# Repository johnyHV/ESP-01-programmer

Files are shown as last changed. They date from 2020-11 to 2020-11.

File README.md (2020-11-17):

# ESP-01-programmer version 1.0
Programmer for module ESP-01

If do you see in Arduino IDE console text "Connecting" then, switch GPIO0 pin to ground, ant push RESET button. 
After sucessfully upload source code to module ESP-01 please disconnect GPIO0 pin from ground, and push RESET button. 
After this step is surce code uploaded in MCU.

# ESP-01 module
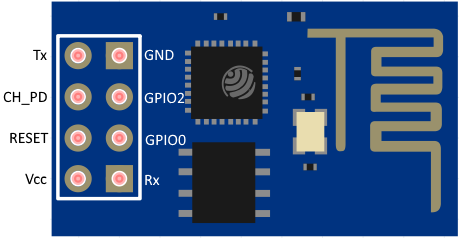
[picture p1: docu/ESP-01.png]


# USB to UART converter
Do you need this USB to UART converter, but please logic level you must set to 5V
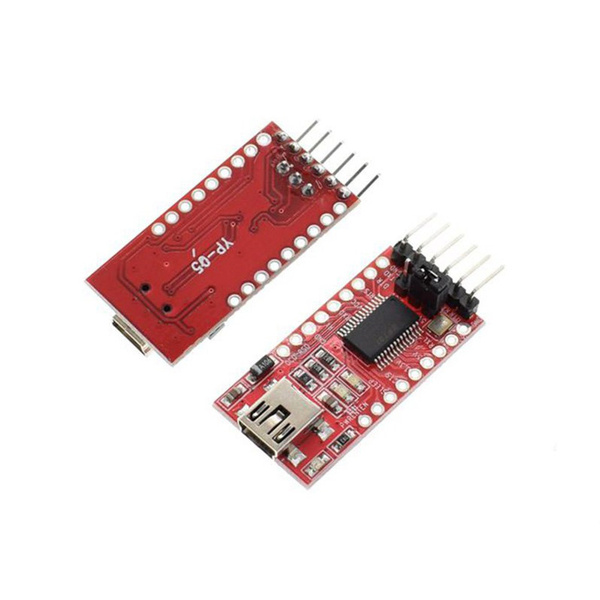
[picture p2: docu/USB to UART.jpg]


# Schematic
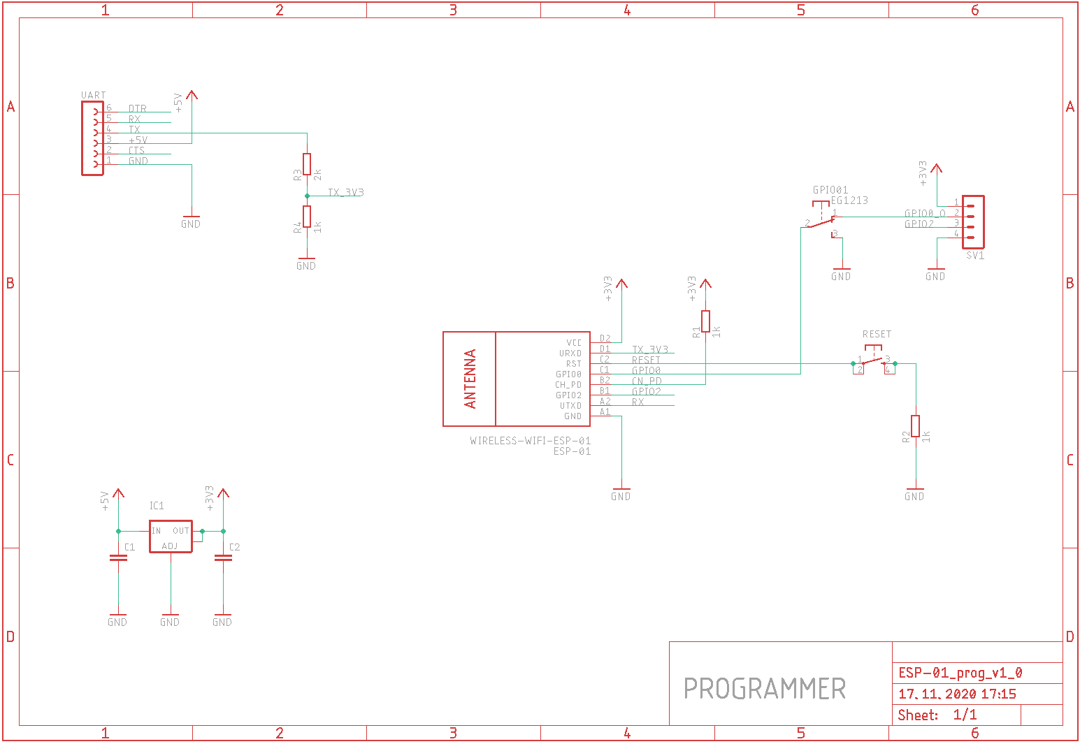
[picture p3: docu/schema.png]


# Programmer board
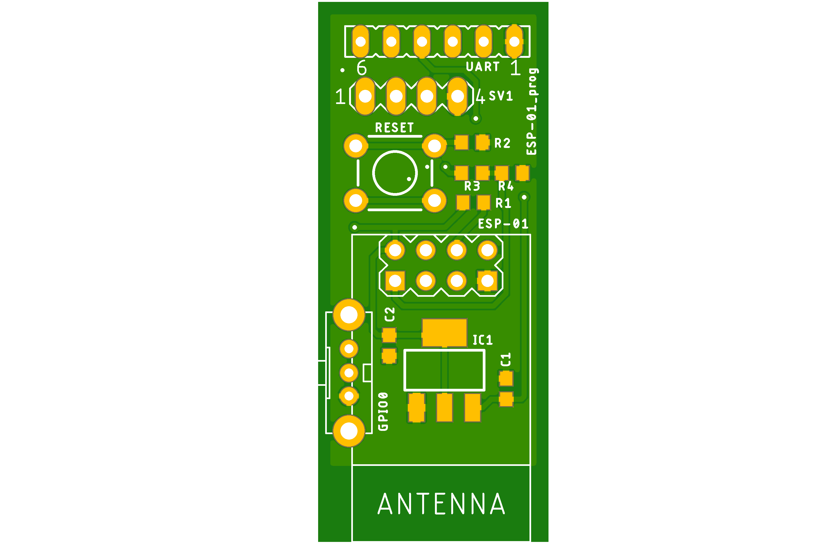
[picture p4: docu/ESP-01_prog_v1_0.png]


# Prototype version
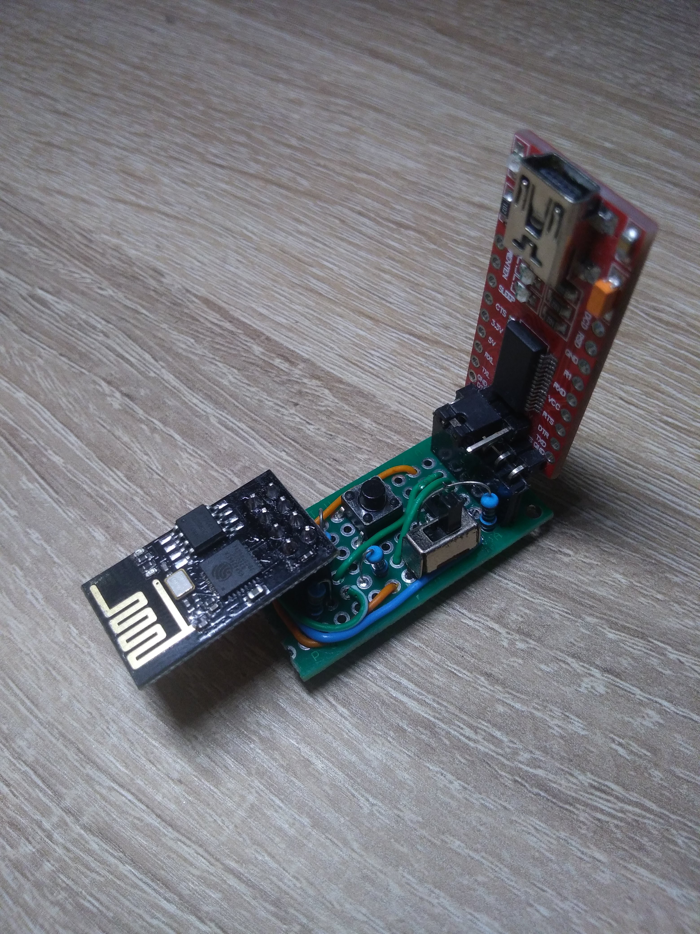
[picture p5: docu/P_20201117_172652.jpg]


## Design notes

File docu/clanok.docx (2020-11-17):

# Ako naprogramovať WI-FI čip ESP-01

Existuje veľké množstvo modulov s WI-FI čipom ESP8266, s rôznymi veľkosťami. Mňa zaujala najmenšia verzia modulu s čipom ESP8266 , a to konkrétne modul ESP-01. Tento modul je zaujímavý svojou veľkosťou a parametrami.

Opis modulu

- Veľkosť modulu približne 25x15mm
- WI-FI čip ESP8266
- veľkosť FLASH pamäte 1MB vo verzii s čiernou doskou od AI-cloud a 512kb v modrej verzii PCB, základnej manufaktúrnej verzii.
- Veľkosť sRAM pamäte 80KB
- Napájacie napätie 3,3V
- Logická úroveň pre GPIO 3,3V
- Podpora WI-FI noriem 802.11/b/g/n
- Integrovaný TCP/IP protokol stack
- Podpora WI-FI security WPA, WPA2
- 2x digitálny vstup/vystup


# Opis

Základná verzia ESP-01 od Ai-cloud používa AT príkazy pre komunikáciu s externým MCU. V tejto verzii je už napálený firmware v ESP-01, ktorý využíva pre komunikáciu s okolitým svetom AT príkazy cez UART rozhranie. Zoznam týchto AT príkazov nájdete na internete. Tieto AT príkazy podporujú napríklad pripojenie modulu k WI-FI sieti, vytvorenie AP z WI-FI modulu, pripojenie sa na TCP-IP server, pripojenie na http server, a veľa ďalšieho. V prípade, že chcete do spomínaného ESP-01 dostať vlastný firmware, a používať MCU ESP-8266 ako štandardný MCU, musíte si vyrobiť vlastný programátor. Jestvuje veľa čínskych programátorov pre ESP-01 modul, ale na tie si musíte dať pozor. Základným dôvodom je, že v čínskych e-shopoch označia za ESP-01 programátor dosku, ktorá nie je programovacia, ale je to iba USB-UART prevodník, pre prácu s AT príkazmi. Nezabudnite si dať pozor na spotrebu prúdu pre modul. MCU ESP-8266 sa považuje za „low power WI-FI MCU“, keďže môže mať v „Deep-Sleep“ móde spotrebu okolo 10uA. No pri maximálnom vyťažení môže byť spotreba prúdu až 170mA počas komunikácie s WI-FI sieťou.

# Schéma zapojenia

Schéma zapojenia pozostáva z jedného prepínača, tlačidla, stabilizátora napätia a pár rezistorov.


Stabilizátor napätia je potrebný, keďže ESP-01 potrebuje napájacie napätie 3,3V. Komunikácia s ESP-01 cez UART rozhranie tiež prebieha na napäťovej úrovni 3,3V. Pozor, štandardné Arduino komunikuje logickou úrovňou 5V, čo môže nenávratne poškodiť ESP-01 modul. Z toho dôvodu je potrebné na RX vstup modulu ESP-01 použiť napäťový delič, ktorý spraví z 5V približne 3,3V. Existujú špeciálne integrované obvody „logic level convertor“ pre upravenie napäťových úrovní, avšak v tomto prípade je postačujúci napäťový delič. Na TX výstup modulu ESP-01 nie je potrebné pridávať nič, keďže 3,3V je stále v tolerancii. Ďalej je použitý jeden prepínač, ktorým určujeme či budeme modul programovať, alebo s ním komunikovať, a taktiež tlačidlo RESET.

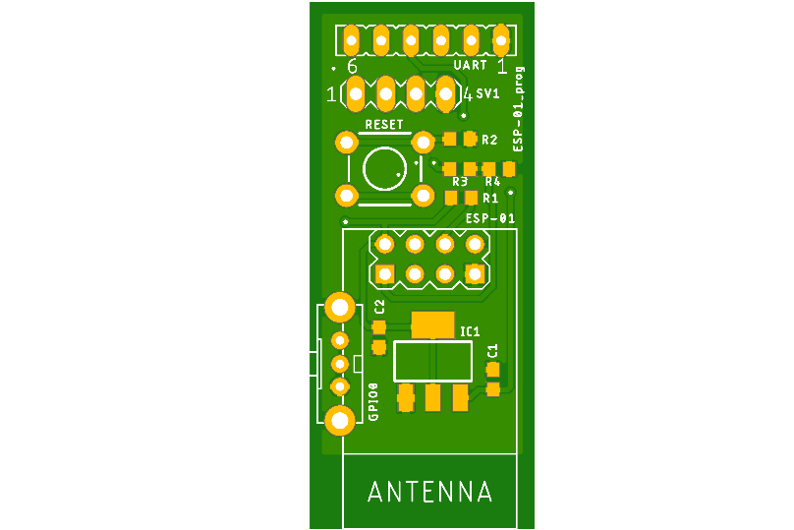
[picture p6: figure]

# Konštrukcia

Pre komunikáciu s programátorom, použijeme štandardný čínsky USB to UART prevodník, s možnosťou nastavenia logickej napäťovej úrovne. Možnosť nastavenia logickej úrovne v tomto prípade nevyužijeme. Tento prevodník využíva FT232RL čip, ale nie je vždy dodaný s originálnym čipom.


Aktuálne nemám vyrobený plošný spoj, takže som si konštrukciu osadil a otestoval na univerzálnom spájkovacom poli. Výsledný efekt so zapojeným prevodníkom a WI-FI modulom je nasledovný:

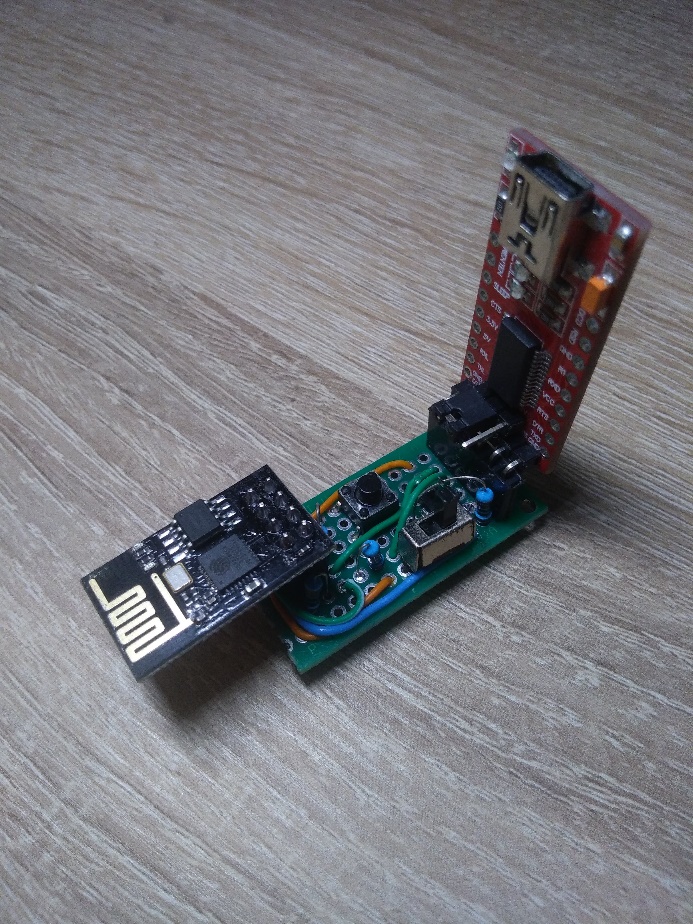
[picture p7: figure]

# Použitie

USB to UART prevodník nastavíme na logickú úroveň 5V. Vďaka tomu budeme mať na výstupe napájacie napätie z prevodníka 5V, a aj komunikáčnú logickú úroveň na 5V.

Ďalej si doinštalujeme podporu ESP8266 MCU do Arduino IDE. Nájdeme to v časti „tools-> Board -> Board manager“ kde do vyhľadávača napíšeme ESP8266 a následne si nainštalujeme podporu ESP8266 modulov.

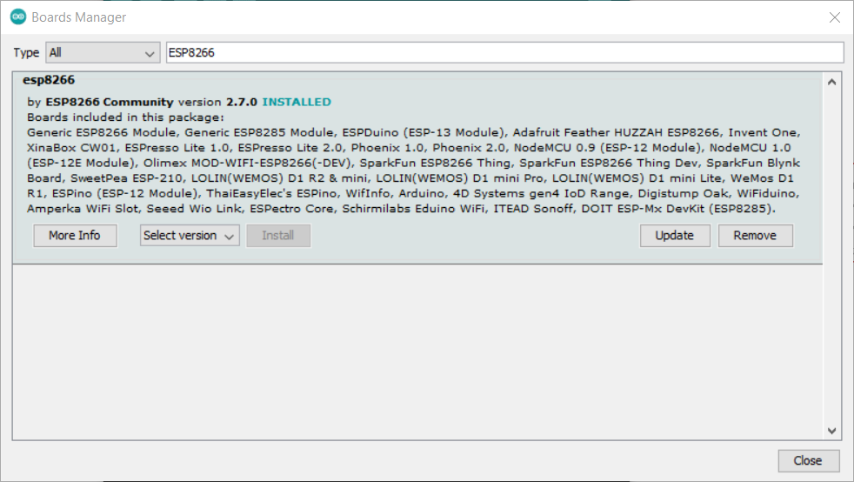
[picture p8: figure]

Následne si v časti „tools->board“ vyberieme dosku „Generic ESP8266“

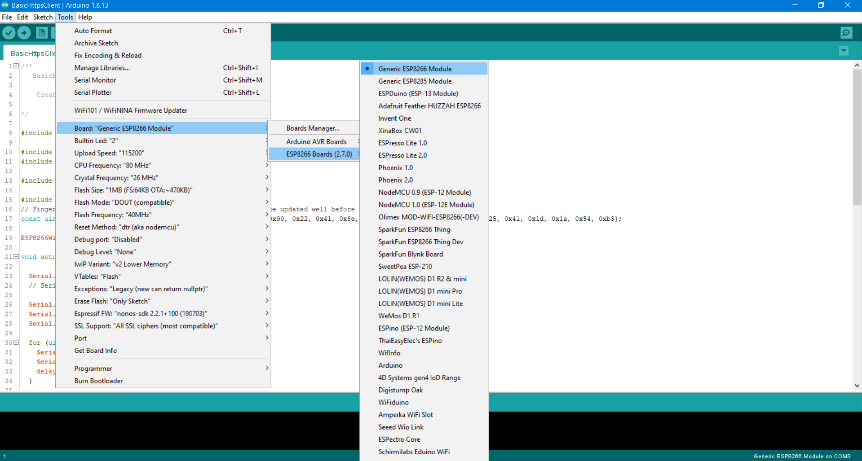
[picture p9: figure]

Môžeme si napríklad otvoriť example pre http WEB server, z „file->example->ESP8266WebServer->HelloServer“. Ostáva už iba upraviť prihlasovacie údaje pre vašu WI-FI sieť, skompilovať zdrojový kód a nahrať ho do modulu ESP-01.

Pred tým ako spustíme nahrávanie zdrojového kódu do modulu ESP-01, musíme prepnúť prepínač GPIO01 do polohy, kedy bude uzemnený GPIO01 pin. Potom stlačíme tlačidlo v Arduino IDE pre začatie kompilovania a nahrávania zdrojového kódu do MCU. Po kompilácii uvidíme v konzole, ako sa Arduino IDE pokúša spojiť s modulom ESP-01.

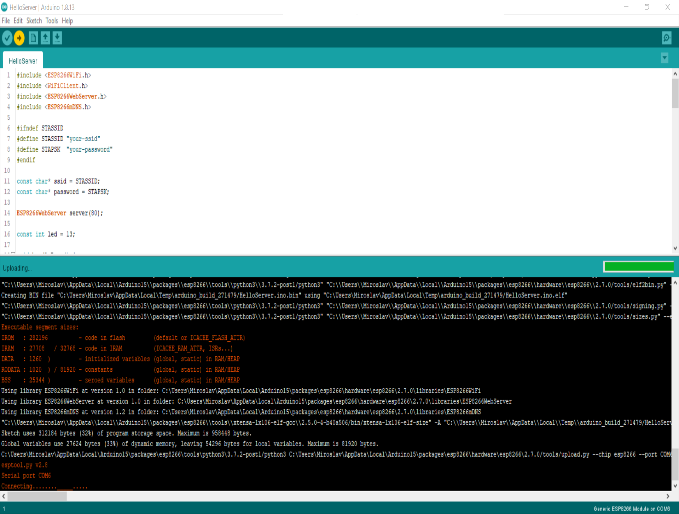
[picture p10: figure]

V poslednom riadku nasledujúceho okna si môžete všimnúť text „Connecting“ a ako pribúdajú bodky a podtržníky. Vtedy stlačíme tlačidlo RESET, a mali by sme vidieť ako sa spustilo nahrávanie zdrojového kódu do modulu ESP-01.

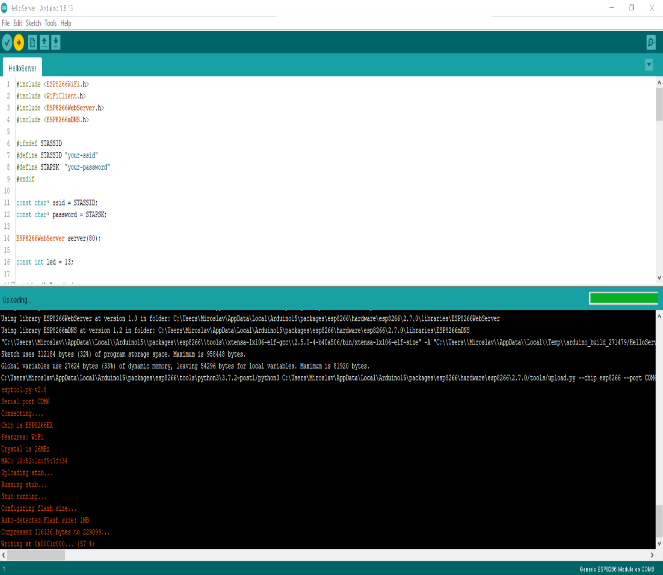
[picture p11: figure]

Na obrázku vidíme, že prebieha nahrávanie zdrojového kódu. Po nahratí zdrojového kódu do modulu ESP-01 uvidíme hlášku „Hard reseting via RTS pin...“

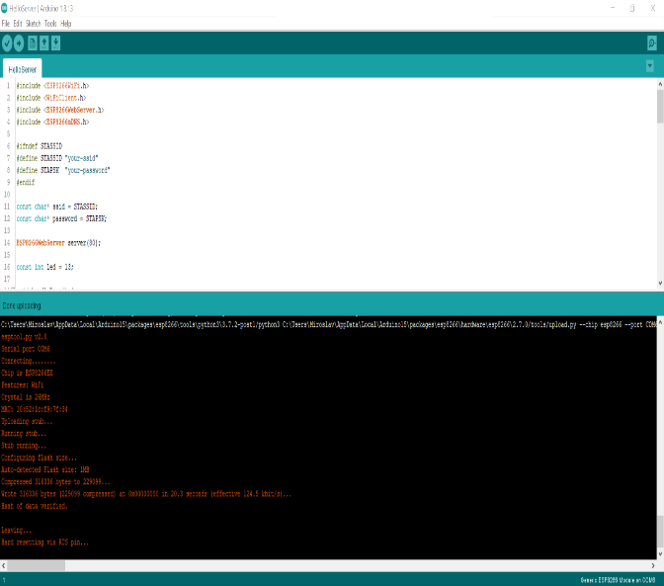
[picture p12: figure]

Potom prepneme prepínač GPIO01 do polohy, kedy GPIO01 pin nie je spojený so zemou a stlačíme tlačidlo RESET, pre reset modulu ESP-01. Po tejto sekvencii nabootuje modul ESP-01 s naším zdrojovým kódom, a je možné pozerať výstup sériovej konzoly napríklad v monitore cez Arduino IDE.

Aktuálny programátor využíva externý USB to UART prevodník a prepínač s tlačidlom pre programovanie. Pracujem na vývoji PCB, kde bude USB to UART prevodník už na doske, kde táto doska bude používať automaticky reset MCU a nastavenie pinov pre programovanie MCU ESP8266.

V prípade, ak by ste mali záujem o plošné spoje programátora ma môžete kontaktovať.

# Odkazy

Zdrojový kód, potrebné knižnice, návrh PCB, schému a všetky potrebné podklady nájdete v mojom git repozitári.

# Kontakt

miroslav.pivovarsky@gmail.com

Ďakujem za prečítanie článku, dúfam že vás konštrukcia zaujala.

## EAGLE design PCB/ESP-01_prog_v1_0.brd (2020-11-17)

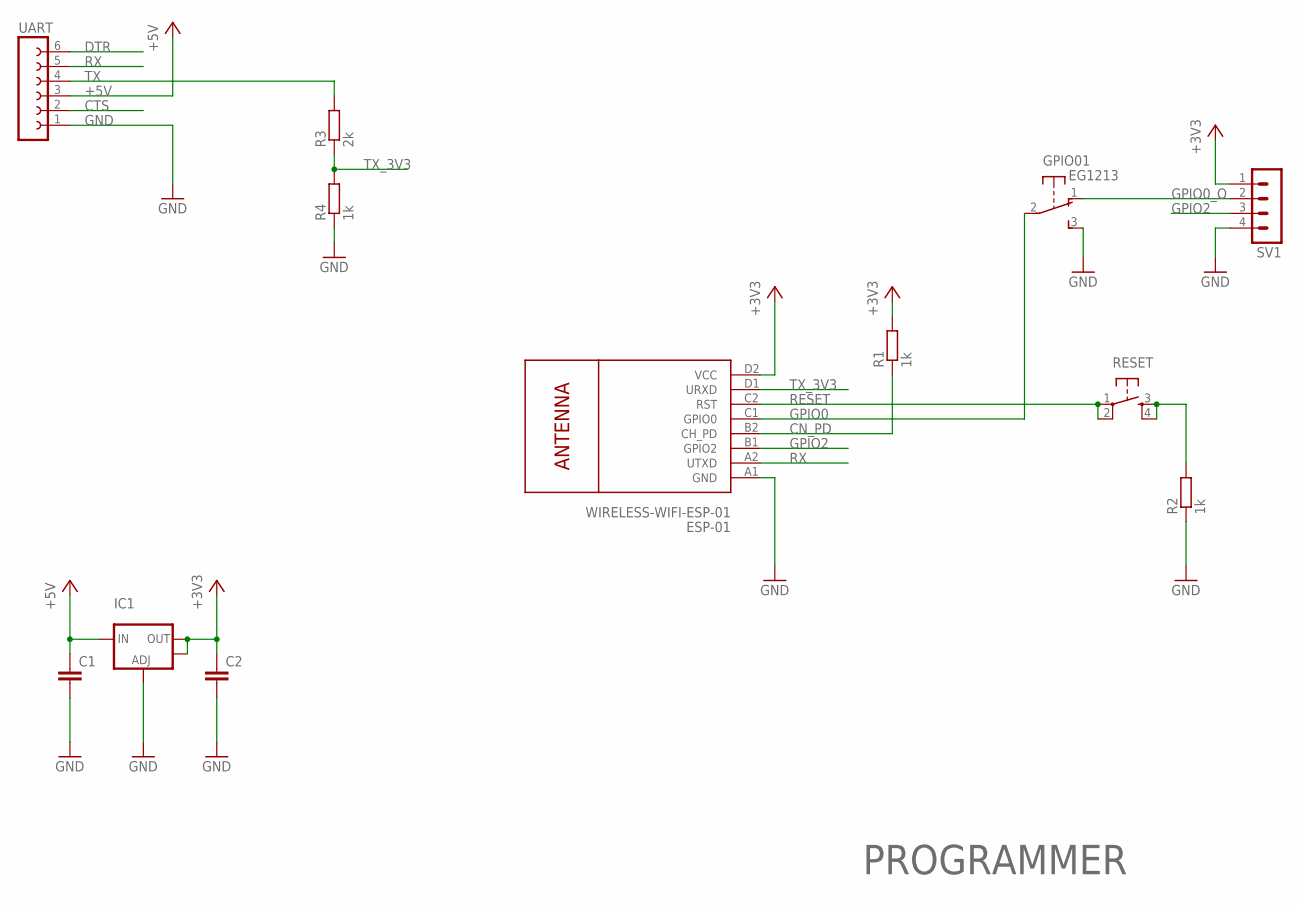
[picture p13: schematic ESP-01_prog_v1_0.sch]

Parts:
C1, C2: C-EUC0603; C0603
ESP-01: WIRELESS-WIFI-ESP-01
GPIO0: EG1213
IC1: LM1117SOT223; SOT223
R1, R2, R4: 1k; R0603
R3: 2k; R0603
RESET: TAC_SWITCHPTH; TACTILE-PTH
SV1: MA04-1
UART: FE06-1; FE06

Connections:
+3V3: C2.1, ESP-01.D2 (VCC), IC1.2 (OUT), IC1.4 (OUT), R1.2, SV1.1
+5V: C1.1, IC1.3 (IN), UART.3
CN_PD: ESP-01.B2 (CH_PD), R1.1
CTS: UART.2
DTR: UART.6
GND: C1.2, C2.2, ESP-01.A1 (GND), GPIO0.3 (S), IC1.1 (ADJ), R2.1, R4.1, SV1.4, UART.1
GPIO0: ESP-01.C1 (GPIO0), GPIO0.2
GPIO0_O: GPIO0.1 (O), SV1.2
GPIO2: ESP-01.B1 (GPIO2), SV1.3
unnamed: R2.2, RESET.3, RESET.4
RESET: ESP-01.C2 (RST), RESET.1, RESET.2
RX: ESP-01.A2 (UTXD), UART.5
TX: R3.2, UART.4
TX_3V3: ESP-01.D1 (URXD), R3.1, R4.2

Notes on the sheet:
PROGRAMMER

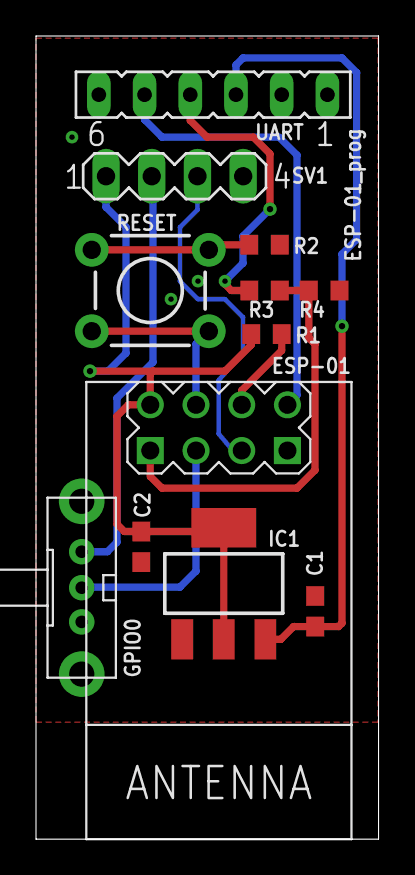
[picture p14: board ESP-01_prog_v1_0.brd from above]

Board: 2 copper layers, 19.0 x 44.6 mm, 12 parts (0 on the bottom side), 12 nets.

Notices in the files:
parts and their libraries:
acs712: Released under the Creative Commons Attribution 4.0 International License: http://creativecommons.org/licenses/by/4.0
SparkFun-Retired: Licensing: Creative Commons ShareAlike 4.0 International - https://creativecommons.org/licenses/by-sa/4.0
